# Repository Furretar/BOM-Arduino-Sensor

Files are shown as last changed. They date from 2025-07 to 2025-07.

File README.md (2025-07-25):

# BOM-Arduino-Sensor
Pressure, temperature, and humidity sensor using an Arduino Uno microcontroller and a display.

## Materials for 1 humidity, temperature, and pressure sensor

| Item | Quantity | Cost (USD) | Link |
|---|---|---|---|
| Electronics Component Fun Kit | 1<br>(enough for 3 builds) | 13.98 | [Amazon](https://www.amazon.com/REXQualis-Electronics-tie-Points-Breadboard-Potentiometer/dp/B073ZC68QG) |
| ARDUINO Uno | 1 | 27.60 | [Amazon](https://a.co/d/ct9kYeS) |
| SSCSRNN1.6BA7A3 pressure sensor | 1 | 58.74 | [Digikey](https://www.digikey.com/short/wj780tdv) |
| SHT85 humidity sensor | 1 | 28.30 | [Digikey](https://www.digikey.com/en/products/detail/sensirion-ag/SHT85/9666378) |
| 3.5" TFT 320x480 + Touchscreen Breakout Board | 1 | 39.95 | [Adafruit](https://www.adafruit.com/product/2050) |
| DS3231 RTC Module 2-pack | 1 (enough for 2 builds) | 5.59 | [Amazon](https://a.co/d/eaZFmYb) |

## Fritzing diagram
bom sensor 2_bb

## Picture of finished electronics (no housing)



Every time the data logging scripts are run, the time on the arduino is set, causing the display to refresh.

## Arduino external documentation
### Libraries used:
    // for TFT display communication (hardware SPI)
    #include <SPI.h> 
    // for I2C communication with both sensors
    #include <Wire.h> 
    // core graphics library
    #include "Adafruit_GFX.h" 
    // library for HX8357D TFT controller
    #include "Adafruit_HX8357.h" 
    // library for SHT85
    #include "Adafruit_SHT31.h"

### Data conversions:
Raw pressure:  
    First 2 bits of the high byte are unneeded and masked using 0x3F (00111111)  
    Then the high byte is shifted to make room for the low byte (00111111 -> 00111111 00000000)
    ((highByte & 0x3F) << 8) | lowByte  

FSS (Full scale scan) value:  
    Current pressure reading as a percentage of the sensor's Full Scale Span  
    Min/max and span values are in the data sheet  
    ((float)rawPressure - SSC_OUTPUT_MIN_RAW(1638.0)) * 100.0 / SSC_DIGITAL_SPAN(14746.0 - 1638.0)

PSI value:  
    SSC_P_MIN(1638.0) + (pressurePercentFSS / 100.0) * (SSC_P_MAX(14746.0) - SSC_P_MIN(1638.0))

MMHg value:  
    pressureValuePSI * PSI_TO_MMHG_FACTOR(51.715)

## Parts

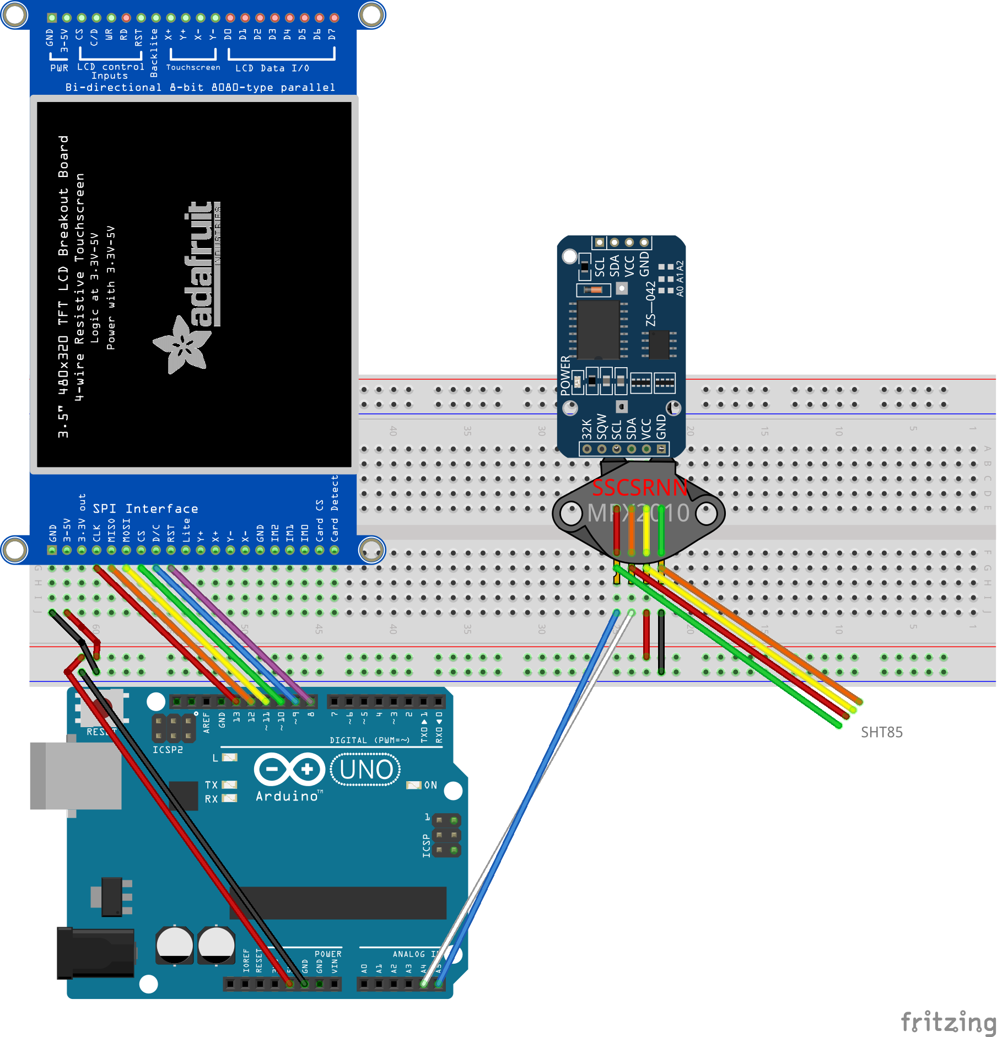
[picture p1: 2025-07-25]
bom sensor 2_bb.png

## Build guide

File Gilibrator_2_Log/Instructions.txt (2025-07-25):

Open Tera Term
Select Serial
Select COM with Gilibrator 2
Press Ok
Before you connect the Gilibrator, make sure the first data logged is not sample 1
	The first sample prints extra data which is not handled currently
File > Log...
Set Filename/Directory to the same as the script (Ex. W:\BOM-Arduino-Sensor\Gilibrator_2_Log\teraterm.log)
	Make sure Timestamp is not selected
	Name must be "teraterm.log"
Press Ok
Run "Gilibrator_2_Log.py"
	To run the python script in the console, navigate to its directory in cmd and type 'py Gilibrator_2_Log.py'
	If access is denied, try unplugging and replugging the Arduino or Gilibrator
Generate readings using Gilibrator 2, they should appear in the console, and is saved to "bom_sensor_data.csv"
	Make sure the "teraterm.log" is generated in the same directory as the exe
	If the data is not printing in the script, delete the teraterm.log file and reconnect to teraterm
If the script hangs or still doesn't log any data, try restarting the computer

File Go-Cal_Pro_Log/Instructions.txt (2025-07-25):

Open Tera Term
Select Serial
Select COM with GoCal Pro
Press Ok
	Confirm data is being logged in Tera Term at this step
File > Log...
Set Filename/Directory to the same as the script (Ex. W:\BOM-Arduino-Sensor\Go-Cal_Pro_Log\teraterm.log)
	Make sure Timestamp is selected
	Name must be "teraterm.log"
Press Ok
Run "Go-Cal_Pro_Log.py"
	To run the python script in the console, navigate to its directory in cmd and type "py 'Go-Cal_Pro_Log.py'"
	If access is denied, try unplugging and replugging the Arduino or Go-Cal Pro
The data should appear in the console, and is saved to "bom_sensor_data.csv"
	Make sure the "teraterm.log" is generated in the same directory as the exe
If the script hangs or still doesn't log any data, try restarting the computer

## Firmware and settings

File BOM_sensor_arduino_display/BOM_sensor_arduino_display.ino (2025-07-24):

#include <SPI.h>
#include <Wire.h>
#include <RTClib.h>
#include <Adafruit_GFX.h>
#include <Adafruit_HX8357.h>
#include <Adafruit_SHT31.h>

// TFT setup
#define TFT_CS   10
#define TFT_DC    9
#define TFT_RST   8
Adafruit_HX8357 tft = Adafruit_HX8357(TFT_CS, TFT_DC, TFT_RST);

// RTC & sensors
RTC_DS3231 rtc;
Adafruit_SHT31 sht31 = Adafruit_SHT31();

// SSC Pressure Sensor constants
const int   SSC_I2C_ADDR = 0x78;
const float SSC_P_MIN = 0.0;
const float SSC_P_MAX = 23.21;
const float PSI_TO_MMHG = 51.715;
const float SSC_MIN_RAW = 1638.0;
const float SSC_MAX_RAW = 14746.0;
const float SSC_RAW_SPAN = SSC_MAX_RAW - SSC_MIN_RAW;

// Text sizes
const int TEXT_SIZE_DATA = 4;
const int TEXT_SIZE_TIME = 4;

float rawToMmHg(uint16_t raw) {
  float pct = (raw - SSC_MIN_RAW) * 100.0 / SSC_RAW_SPAN;
  float psi = SSC_P_MIN + pct/100.0 * (SSC_P_MAX - SSC_P_MIN);
  return psi * PSI_TO_MMHG;
}

void setup() {
  Serial.begin(115200);
  while (!Serial);

  Wire.begin();
  if (!rtc.begin()) {
    Serial.println("RTC not found!");
    while (1) delay(10);
  }

  // Wait for SETTIME from PC
  Serial.println("waiting for SETTIME...");

  // SHT31 init
  if (!sht31.begin(0x44)) {
    Serial.println("SHT31 not found!");
    while (1) delay(10);
  }

  // TFT init
  tft.begin();
  tft.setRotation(0);
  tft.fillScreen(HX8357_WHITE);
  tft.setTextColor(HX8357_BLACK, HX8357_WHITE);
  tft.setTextSize(4);
  tft.setCursor(10,  10); tft.println("Pressure:");
  tft.setCursor(10, 120); tft.println("Temp:");
  tft.setCursor(10, 230); tft.println("Humidity:");
}

void loop() {
  // Handle time setting over Serial
  if (Serial.available()) {
    String cmd = Serial.readStringUntil('\n');
    if (cmd.startsWith("SETTIME")) {
      int yyyy, MM, dd, hh, mm, ss;
      sscanf(cmd.c_str(), "SETTIME %d-%d-%d %d:%d:%d", &yyyy, &MM, &dd, &hh, &mm, &ss);
      rtc.adjust(DateTime(yyyy, MM, dd, hh, mm, ss));
      Serial.println("setting time and date");
    }
  }

  DateTime now = rtc.now();

  char dateStr[11], timeStr[9];
  snprintf(dateStr, sizeof(dateStr), "%04d-%02d-%02d", now.year(), now.month(), now.day());
  snprintf(timeStr, sizeof(timeStr), "%02d:%02d:%02d", now.hour(), now.minute(), now.second());

  // Read pressure
  Wire.requestFrom(SSC_I2C_ADDR, (uint8_t)2);
  float mmHg = NAN;
  if (Wire.available() == 2) {
    uint8_t hb = Wire.read(), lb = Wire.read();
    uint16_t raw = ((hb & 0x3F) << 8) | lb;
    mmHg = rawToMmHg(raw);
  }

  // Read temp + humidity
  float tempC = sht31.readTemperature();
  float hum   = sht31.readHumidity();

  // Serial output
  Serial.print(dateStr);
  Serial.print("  ");
  Serial.print(timeStr);
  Serial.print("  |  ");
  Serial.print(mmHg, 2);  Serial.print(" mmHg, ");
  Serial.print(tempC, 2); Serial.print(" C, ");
  Serial.print(hum, 2);   Serial.println(" %");

  // TFT pressure
  tft.fillRect(10,  60, 200, 35, HX8357_WHITE);
  tft.setCursor(10,  60);
  tft.setTextSize(TEXT_SIZE_DATA);
  tft.setTextColor(HX8357_RED, HX8357_WHITE);
  if (!isnan(mmHg)) {
    tft.print(mmHg, 2);
    tft.print("mmHg");
  } else {
    tft.print("ERR");
  }

  // TFT temp
  tft.fillRect(10, 170, 200, 35, HX8357_WHITE);
  tft.setCursor(10, 170);
  tft.print(isnan(tempC) ? 0.0 : tempC, 2);
  tft.print("C");

  // TFT humidity
  tft.fillRect(10, 280, 200, 35, HX8357_WHITE);
  tft.setCursor(10, 280);
  tft.print(isnan(hum) ? 0.0 : hum, 2);
  tft.print("%");

  // TFT clock
  tft.setTextSize(TEXT_SIZE_TIME);
  tft.setTextColor(HX8357_BLACK, HX8357_WHITE);
  tft.fillRect(10, 350, 220, 60, HX8357_WHITE);
  tft.setCursor(10, 350);       tft.print(dateStr);
  tft.setCursor(10, 390);       tft.print(timeStr);

  delay(1000);
}

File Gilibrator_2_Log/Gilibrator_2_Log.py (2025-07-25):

import serial, csv, re, time, os
from datetime import datetime, timedelta
from serial.tools import list_ports

FORCE_PORT = None  # e.g. "COM4"

def find_serial_port():
    if FORCE_PORT:
        try:
            test_ser = serial.Serial(FORCE_PORT)
            test_ser.close()
            print("Using forced port:", FORCE_PORT)
            return FORCE_PORT
        except serial.SerialException as e:
            raise SystemExit(f"Forced port {FORCE_PORT} failed to open: {e}")

    ports = list_ports.comports()
    arduinos = [p.device for p in ports if "Arduino" in p.description]
    candidate_ports = arduinos if arduinos else [p.device for p in ports]

    if not candidate_ports:
        raise SystemExit("No serial ports found!")

    print("Detected serial ports:", candidate_ports)

    for p in candidate_ports:
        try:
            test_ser = serial.Serial(p)
            test_ser.close()
        except serial.SerialException:
            continue

        while True:
            print(f"\nFound working port: {p}")
            user_input = input("Press Enter to skip, or type 'y' to use this port: ").strip().lower()
            if user_input == "y":
                print("Using port:", p)
                return p
            elif user_input == "":
                break

    raise SystemExit("No usable serial ports selected.")

port = find_serial_port()
baud = 115200

tera_path = "teraterm.log"
tera_triplet_pattern = re.compile(r"(\d+(?:\.\d+)?)\s+(\d+(?:\.\d+)?)\s+(\d+(?:\.\d+)?)")


out_file = "bom_sensor_data.csv"

first_time = not os.path.exists(out_file) or os.stat(out_file).st_size == 0
f_out = open(out_file, "a", newline="")
writer = csv.writer(f_out)
if first_time:
    writer.writerow([
        "Timestamp",
        "Pressure(mmHg)",
        "Temperature(C)",
        "Humidity(%)",
        "Flow",
        "AverageFlow",
        "SampleNumber"
    ])

tera_entries = []
tera_pos = 0
pump_f = None

def reload_new_tera():
    global pump_f, tera_pos, tera_entries, tera_path

    if not os.path.exists(tera_path):
        pump_f = None
        return

    try:
        stat = os.stat(tera_path)
        current_size = stat.st_size
        current_mtime = stat.st_mtime
    except Exception:
        return

    if pump_f is None or pump_f.closed:
        pump_f = open(tera_path, "r")
        tera_pos = 0
        tera_entries.clear()

    elif tera_pos > current_size:
        print("TeraTerm log was truncated or rotated. Reopening.")
        pump_f.close()
        pump_f = open(tera_path, "r")
        tera_pos = 0
        tera_entries.clear()

    pump_f.seek(tera_pos)
    new_data = pump_f.read()
    tera_pos = pump_f.tell()

    if not new_data.strip():
        return

    # print(f"Detected new TeraTerm log data: {new_data}")

    matches = tera_triplet_pattern.findall(new_data)
    # print("Detected new TeraTerm log data joined:", ' '.join(f"{a} {b} {c}" for a, b, c in matches))
    for flow, avg_flow, sample_str in matches:
        sample_num = int(sample_str)
        flow_val = float(flow)
        avg_flow_val = float(avg_flow)
        if tera_entries and sample_num <= tera_entries[-1][0]:
            continue
        tera_entries.append((sample_num, flow_val, avg_flow_val))




ser = serial.Serial(port, baud, timeout=2)
time.sleep(2)

adjusted_time = datetime.now() + timedelta(seconds=0)
time_sync_cmd = f"SETTIME {adjusted_time.strftime('%Y-%m-%d %H:%M:%S')}\n"
ser.write(time_sync_cmd.encode())

reply = ser.readline().decode().strip()
print(f"Sent time sync: {time_sync_cmd.strip()}")
print(f"Arduino replied: {reply}")

print(f"Logging to {out_file}, showing latest flow from TeraTerm. Ctrl+C to quit.")
print(f"Arduino Timestamp   |Pressure(mmHg)|Temperature(C)|Humidity(%)|Flow        |AverageFlow    |SampleNumber")

# On startup, ignore printing any existing sample by initializing to highest sample present
last_sample_num_printed = None

# Preload existing tera entries once to get current highest sample number
if os.path.exists(tera_path):
    with open(tera_path, "r") as f:
        content = f.read()
    matches = tera_triplet_pattern.findall(content)
    for flow, avg_flow, sample_str in matches:
        sample_num = int(sample_str)
        flow_val = float(flow)
        avg_flow_val = float(avg_flow)
        if tera_entries and sample_num <= tera_entries[-1][0]:
            continue
        tera_entries.append((sample_num, flow_val, avg_flow_val))

if tera_entries:
    last_sample_num_printed = tera_entries[-1][0]  # ignore printing initial last entry


try:
    while True:
        reload_new_tera()

        line = ser.readline().decode("utf-8", "ignore").strip()
        if "|" not in line:
            continue

        left, right = line.split("|", 1)
        ts_str = left.strip()
        vals = [v.strip().split()[0] for v in right.split(",")]
        if len(vals) < 3:
            continue
        pressure, temp, hum = vals[:3]
        try:
            ts = datetime.strptime(ts_str, "%Y-%m-%d %H:%M:%S.%f")
        except ValueError:
            ts = datetime.strptime(ts_str, "%Y-%m-%d %H:%M:%S")

        flow = avg_flow = sample_num = ""
        if tera_entries:
            sample_num, flow_val, avg_flow_val = tera_entries[-1]
            flow = str(flow_val)
            avg_flow = str(avg_flow_val)

        writer.writerow([
            ts.strftime("%Y-%m-%d %H:%M:%S.%f")[:-3],
            pressure, temp, hum,
            flow, avg_flow, sample_num
        ])
        f_out.flush()

        if sample_num != last_sample_num_printed:
            print(f"{ts_str}|{pressure}        |{temp}         |{hum}  "
                  f"    |{flow}        |{avg_flow}              |{sample_num}")
            last_sample_num_printed = sample_num

except KeyboardInterrupt:
    print("\nStopping.")
finally:
    ser.close()
    f_out.close()
    if pump_f:
        pump_f.close()

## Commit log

2025-07-07 arduino code and fritzing diagram
    [bom sensor.fzz]
2025-07-07 update arduino comments
2025-07-24 fixed logger overwriting data
    [bom sensor 2.fzz, bom sensor.fzz]
2025-07-24 log pump data
2025-07-25 switch port function
2025-07-25 change name
    [bom sensor 2 fritzing.fzz]
